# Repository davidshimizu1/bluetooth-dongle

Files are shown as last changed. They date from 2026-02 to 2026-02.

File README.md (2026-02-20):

<p align="center">
  <h1 align="center">High-Performance Low-Latency Bluetooth 5.0 Dongle</h1>

<p align="center">
  pluggedin
</p>

## Project Overview
This project aimed to design and manufacture a custom Bluetooth 5.0 dongle that exceeds the RF signal integrity and latency performance of commercial off-the-shelf solutions. 
* **Custom 4-Layer PCB:** Designed in Altium Designer with strictly routed, impedance-matched traces for optimal RF performance.
* **Low Latency:** Achieves <20ms latency for real-time input registration.
* **Extended Range:** Verified effective wireless range of up to 280 feet.
* **Precision Enclosure:** Custom-modeled magnetic enclosure (Fusion 360)

---

## Performance & RF Specifications
* **Protocol:** Bluetooth 5.0 (Classic + BLE)
* **Transmit Power:** Up to +8dBm
* **Receive Sensitivity:** -88dBm
* **Effective Latency:** < 20ms
* **Max Range:** ~280 feet (Line of sight)

---

## Hardware & Architecture

### PCB Design (Altium Designer)

<table align="center">
  <tr>
    <td align="center" valign="bottom">
      Isometric View of PCB
      <br><b>Isometric View of PCB</b>
    </td>
    <td align="center" valign="bottom">
      Top View of PCB
      <br><b>Top View of PCB</b>
    </td>
  </tr>
</table>

The board utilizes a 4-layer stackup to ensure proper ground shielding and power delivery. The critical RF pathways were impedance-matched to 50 ohms to prevent signal reflection and detuning, which is a common failure point in compact commercial dongles.

### Mechanical Design (Fusion 360)
  Enclosure Top View
  <br><b>Enclosure Top </b><br><br>
  
  Enclosure Bottom View
  <br><b>Enclosure Bottom </b>
</p>

---

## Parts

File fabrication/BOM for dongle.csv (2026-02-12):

Comment | Description | Designator | Footprint | LibRef | Quantity | LCSC Part #
2.4GHz antenna |  | ANT1 | 2.4GHz antenna | 2.4GHz antenna | 1 | C3283994
1uF | 0402 smd capacitor | C1, C2 | 0402 capacitor | 0402 capacitor | 2 | C52923
USBLC6-2P6 | TVS DIODE 5.25V 17V SOT666 | D1 | FP-SOT-666-MFG | CMP-12225-000058-1 | 1 | C15999
300mA |  | F1 | 0805 polyfuse | 0805 polyfuse | 1 | C22378359
BT850-ST |  | IC1 | BT850-ST | BT850-ST | 1
AP2112K-3.3TRG1 | Integrated Circuit | IC2 | SOT95P285X140-5N | AP2112K-3.3TRG1 | 1 | C51118
9nH |  | L1 | 0402INDUCTOR | 0402 inductor | 1 | C113122
11nH |  | L2 | 0402INDUCTOR | 0402 inductor | 1 | C337934
USB A MALE |  | USB1 | USB A MALE | USB A MALE | 1 | C386752
100nF | "" | C3 | 0402 capacitor | 0402 capacitor | 1 | C1525

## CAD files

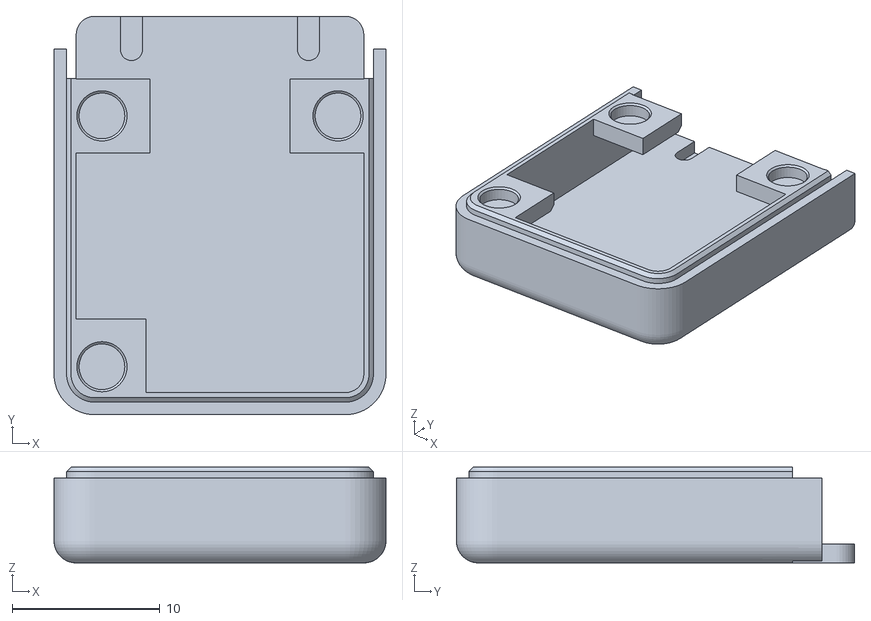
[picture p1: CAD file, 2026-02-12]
3d_models/bottom.stl
22.5 x 27.0 x 6.50

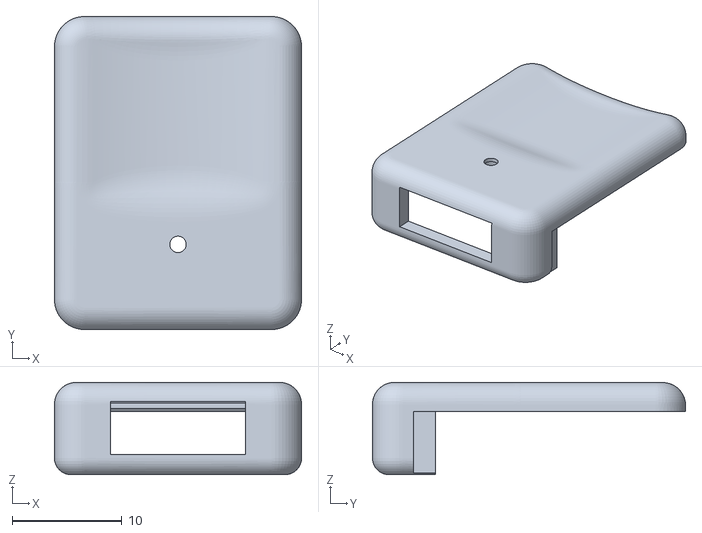
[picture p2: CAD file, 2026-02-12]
3d_models/top.stl
22.5 x 28.5 x 8.40

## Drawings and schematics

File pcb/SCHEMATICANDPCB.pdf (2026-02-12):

USB CONNECTOR + PROTECTION | LINEAR REGULATOR (5V to 3.3V)

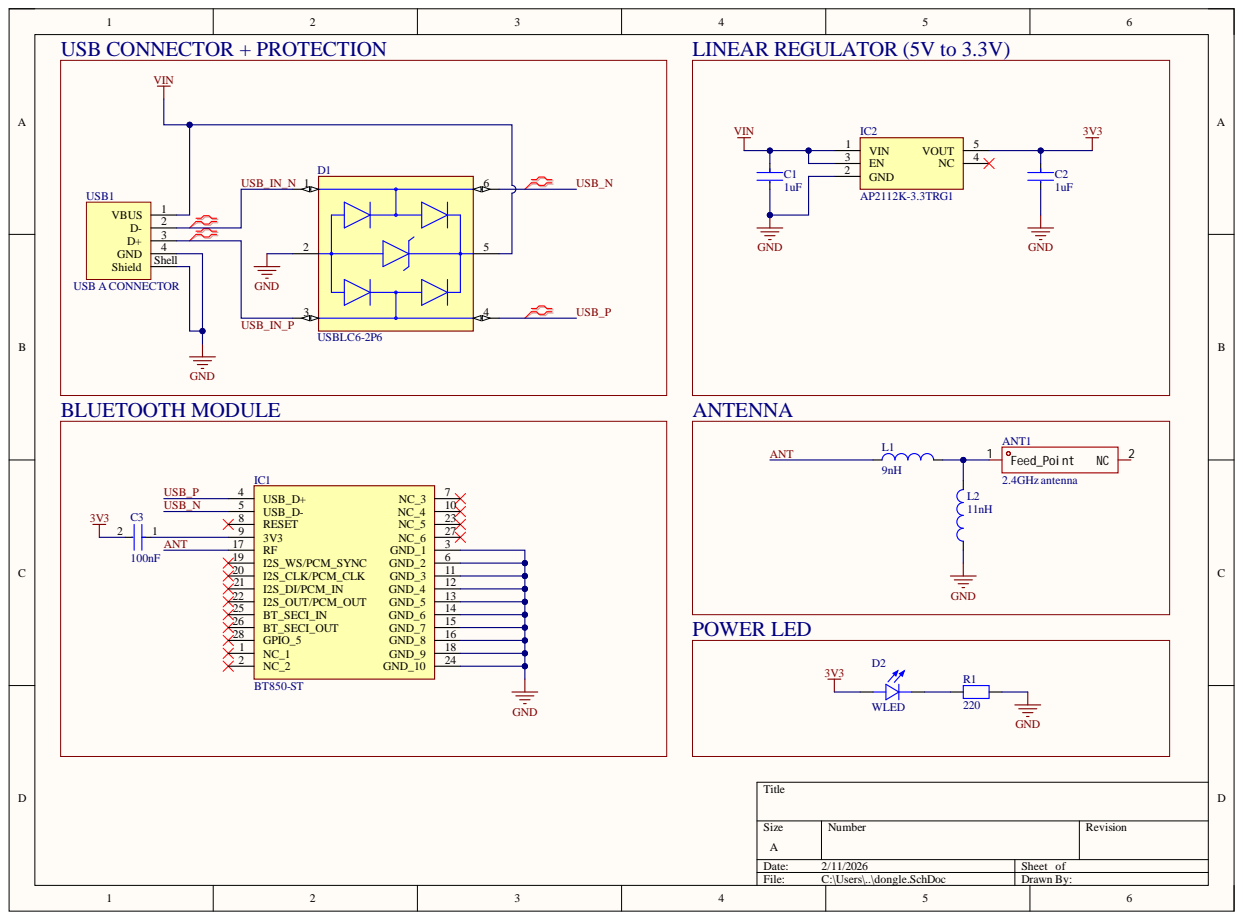
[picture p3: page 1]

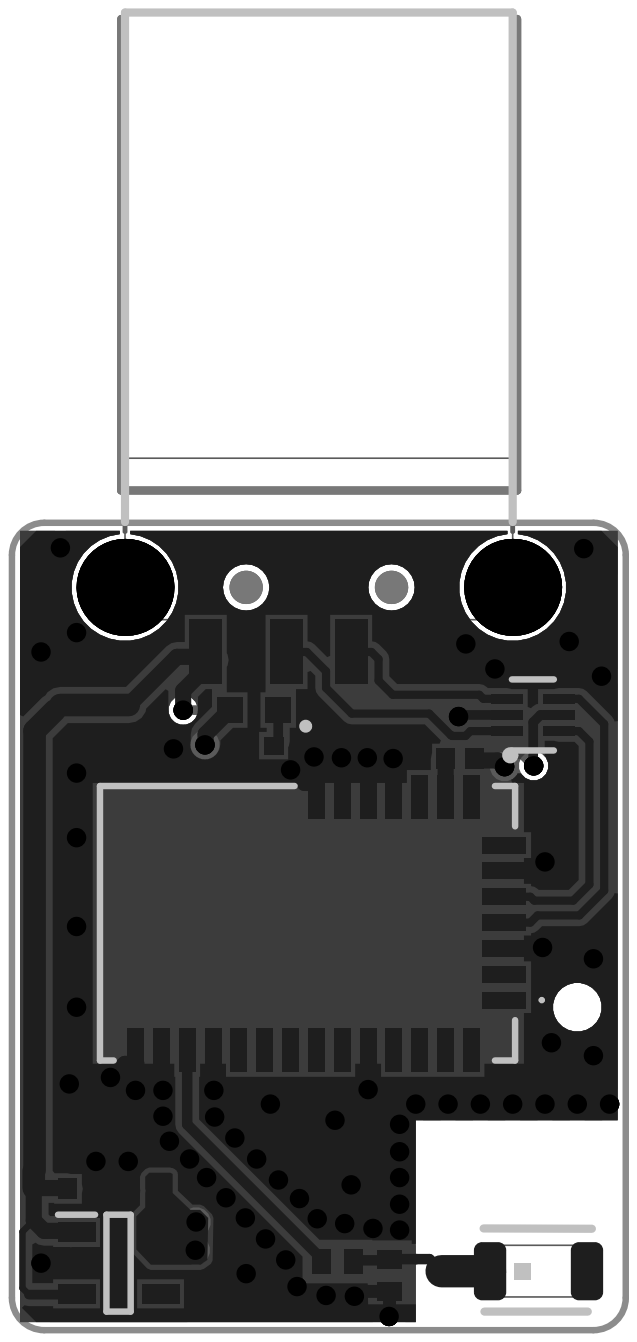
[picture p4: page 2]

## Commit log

2026-02-12 add pcb
2026-02-12 add fab files
    [BOM for dongle.csv, Pick Place for dongle.csv]
2026-02-12 add pdf for pcb and schematic
